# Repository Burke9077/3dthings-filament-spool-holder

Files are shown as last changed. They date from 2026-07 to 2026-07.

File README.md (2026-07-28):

# Parametric filament spool holder

A compact, open-frame filament spool holder designed in OpenSCAD. It takes the
useful layout of common laser-cut desktop holders—a spool axle between two side
frames—and redesigns it as a support-free multipart FDM print.

The model is intentionally unbranded and omits cosmetic panels. Material is
placed only around the load paths, axle cradles, rail sockets, and narrow bottom
ties.

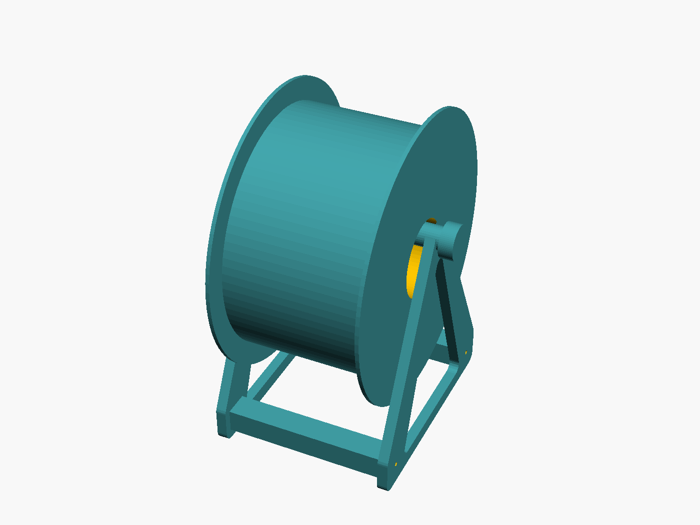
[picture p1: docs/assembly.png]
Rendered assembly


## Browser customizer

Use the hosted customizer at
[burke9077.github.io/3dthings-filament-spool-holder](https://burke9077.github.io/3dthings-filament-spool-holder/).
Set the spool outside diameter, center-hole diameter, and outside width; choose
one to four linked holders; then download the complete print-pack ZIP. The
holder adds side clearance and raises the axle until the complete spool
envelope clears both unchanged crossrails and the table. Advanced controls
expose those clearances, print-bed size, axle diameter, M3 nut dimensions, and
part-fit clearances.

The live 3D assembly rebuilds automatically after settings change. The
part-fit clearance preset changes only mating tolerances—rail sockets, nut
pockets, screw bores, axle caps, and link clips—not print speed, layers,
infill, or strength.

Optional downloads for the nut-fit test, one holder module, link clips, and
individual replacement parts are kept under a secondary menu. Each ZIP carries
the outside diameter, maximum bore, spool width, base depth, crossrail
clearance, and copy counts in its filenames and manifest. The on-page guide
covers print orientation and assembly.

The customizer runs the official OpenSCAD WebAssembly build entirely in the
browser. Dimensions and generated geometry stay on the device; there is no
model-generation server.

## Features

- Parameterized spool outside diameter, center-hole diameter, outside width,
  base depth, rigid-part clearances, frame, axle, fit, and M3 hardware
  dimensions
- Collision-aware axle height derived against the table and complete
  crossrail top plane, with analytic assertions and mesh-level regression
  checks
- Two identical side frames and two identical crossrails
- Shouldered rail tenons that seat in blind inside-face frame sockets
- Drop-in M3 hex-nut traps that become captive inside those sockets
- Removable printed axle with press-fit end caps
- Repeatable side-by-side link clips that preserve independent spool changes
- Flat, support-free print orientations for every part
- Small nut-fit test piece for calibrating a printer before committing to the rails
- Automatically updating browser-side 3D preview
- OpenSCAD Customizer support and command-line STL export

The defaults accept a spool up to 220 mm outside diameter, 60 mm center hole,
and 115 mm outside width. Five millimeters beside each face produces 125 mm
between the frames. The generator guarantees at least 15 mm above the complete
crossrail top plane; that constraint governs the default axle-center height of
172 mm. The worst-case spool bottom is therefore 41 mm above the table and
15 mm above the 26 mm crossrails. The assembly preview shows that maximum
envelope hanging from the axle, just as the physical spool does.

Both diameters matter. The axle supports the upper inside edge of the spool
hole, so the spool center hangs below the axle by half the difference between
the hole and axle diameters. The spool must also clear the crossrails, not
merely the table. The design therefore uses:

```text
spool radius       = outside diameter / 2
rail top           = rail center height + rail height / 2

floor-limited center = spool radius + floor clearance
rail-limited center  = rail top + spool radius + rail clearance

spool center = max(floor-limited center, rail-limited center)
axle height  = spool center
             + (center-hole diameter - axle diameter) / 2
```

The rail rule deliberately treats the entire horizontal plane at the
crossrails' top surface as occupied. This is more conservative than relying on
their lateral position and guarantees that the spool's lowest point clears
both rails even with a non-ideal printed flange. Enter the largest outside
diameter, center hole, and width among the spools you intend to use. Every
spool hole must also be larger than the selected axle diameter.

## Bill of materials

| Item | Quantity | Notes |
| --- | ---: | --- |
| Side frame | 2 | Identical prints |
| Crossrail | 2 | Identical prints; nut openings face upward |
| Axle | 1 | Printed horizontally |
| Axle cap | 2 | Press fit; print closed face on the bed |
| Link clip | 2 per adjacent pair | Optional; one front and one rear |
| M3 hex nut | 4 | Standard 5.5 mm across-flats nut |
| M3 × 10 mm socket-head screw | 4 | M3 × 8 mm also works with most nuts |

## Generate the parts

Open `filament_spool_holder.scad`, choose a value for `part` in the Customizer,
then render and export the STL. Print the quantities listed above.

From a shell with OpenSCAD installed:

```sh
make stls
```

Generated files go into `build/`, which is intentionally not committed. To
regenerate the documentation render:

```sh
make preview
```

## Release preparation

Marketplace publication is held until a complete physical print has been
assembled and approved. The manually triggered **Prepare release** workflow
builds an inspectable release candidate by default; it cannot create a public
GitHub Release without the physical-test confirmation.

See [PUBLISHING.md](PUBLISHING.md) for the release gate, marketplace research,
and first-publication checklist. Build the same candidate locally with:

```sh
make release
```

## Calibrate before printing

Print `build/nut_fit_test.stl` first:

```sh
make build/nut_fit_test.stl
```

A nut should drop into the top opening without rotating in its hex pocket, and
an M3 screw should pass through the horizontal bore. Adjust
`m3_nut_clearance` or `m3_hole_diameter` if needed. The defaults target a
reasonably tuned FDM printer; dimensional behavior varies by material and
machine. In the browser customizer, choose **Extra clearance** when mating
parts bind or **Reduced clearance** when they feel loose.

## Suggested print settings

- 0.20 mm layer height
- 4 top and bottom layers
- 25% gyroid or cubic infill
- PLA, PETG, or ASA
- No supports

Print each side frame flat with its two shallow rail recesses upward. Print each
rail on its broad face with both nut openings upward. The axle has a faceted
flat and is already oriented horizontally; a brim can help with low-adhesion
materials. Print caps with the closed flange against the bed and the socket
upward.

## Assembly

1. Set both crossrails down with their nut openings facing up.
2. Drop an M3 nut into each of the four hex pockets.
3. Seat both shouldered tenons in the shallow recesses on one side frame, then
   add the second frame with its recesses facing inward.
4. Install the four M3 screws through the small holes on the outside faces.
   Square the holder on a flat surface and tighten them evenly.
5. Slide the axle through the spool and lower it into the open cradles. Confirm
   that the axle bears on the upper inside edge of the spool hole while the
   spool clears the floor and both crossrails, then press a cap onto each end.

The blind side-frame sockets cover the nut openings after assembly, so the nuts
cannot escape or turn. The rail shoulders bear against the inside frame faces;
tightening each screw therefore clamps the joint instead of merely retaining
it.

## Link two or more holders

Keep each holder complete, including both side frames and its own axle. Put two
holders side by side, leaving the facing outside frames separated by
`link_gap`, then press one link clip over the two front frame edges and a second
clip over the rear edges. The rounded lower frame corners locate the clips
vertically.

The default 32 mm gap leaves clearance between two facing axle caps. Each
additional holder needs two more clips:

| Holders | Link clips |
| ---: | ---: |
| 1 | 0 |
| 2 | 2 |
| 3 | 4 |
| 4 | 6 |

This deliberately keeps each axle independent. A shared center frame or single
long axle would save one frame, but changing one spool would disturb its
neighbor.

## Important parameters

| Parameter | Default | Purpose |
| --- | ---: | --- |
| `spool_max_diameter` | 220 mm | Largest supported spool outside diameter |
| `spool_max_bore_diameter` | 60 mm | Largest supported spool center hole; contributes to axle height |
| `spool_max_width` | 115 mm | Largest supported width across both outside flanges |
| `spool_side_clearance` | 5 mm/side | Added beside the spool; derives 125 mm clear frame spacing |
| `base_depth` | 175 mm | Front-to-back footprint |
| `spool_floor_clearance` | 15 mm | Minimum vertical gap above the table |
| `spool_rail_clearance` | 15 mm | Minimum vertical gap above the complete crossrail top plane |
| `frame_thickness` | 8 mm | Thickness of each flat side frame |
| `frame_web` | 14 mm | Minimum structural web around the large cutout |
| `axle_diameter` | 18 mm | Printed axle diameter |
| `axle_facets` | 32 | Round axle profile with a narrow printable flat |
| `rail_fit_clearance` | 0.30 mm | Per-side clearance in frame sockets |
| `m3_nut_clearance` | 0.25 mm | Per-side nut-pocket clearance |
| `axle_cap_fit_clearance` | 0.25 mm | Diametral cap socket clearance |
| `link_gap` | 32 mm | Gap between linked modules |
| `link_fit_clearance` | 0.15 mm | Per-side clearance around linked frames |
| `holder_count` | 2 | Complete modules shown in `linked_assembly` |

Changing the outside diameter, center hole, base depth, or either rigid-part
clearance automatically updates the side-frame axle height. Changing spool
width or side clearance updates the rail and axle lengths. OpenSCAD assertions
and generated-mesh collision tests reject combinations that would intersect
the table or crossrails, cut rail sockets through the frame, leave too little
material around the axle, or make the spool hole incompatible with the axle.

## License

The design and customizer are licensed under the [MIT License](LICENSE).

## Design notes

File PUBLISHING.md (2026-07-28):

# Publishing

This project stays unpublished on third-party model sites until a complete
physical print has been assembled and approved.

## Release policy

- Pull requests and merges never publish a marketplace listing.
- GitHub Releases are the canonical, versioned source for generated files.
- The **Prepare release** workflow defaults to a build-only candidate.
- Creating a public GitHub Release requires all of:
  - running the workflow from `main`;
  - a semantic version such as `v0.1.0`;
  - enabling the `publish_release` input; and
  - entering the exact confirmation `PHYSICALLY_TESTED`.
- Publishing or updating Thingiverse and Printables remains a separate,
  deliberate operation.

This keeps a code review or routine Pages deployment from becoming a product
release.

## Build a release candidate

Open **Actions → Prepare release → Run workflow**.

For a build-only rehearsal:

1. Leave `version` as `unreleased`.
2. Leave `publish_release` disabled.
3. Run the workflow.
4. Download and inspect the `spool-holder-release-unreleased` artifact.

The artifact contains the default 220 mm outside-diameter × 60 mm maximum-bore
× 115 mm spool-width STLs (125 mm clear frame spacing), OpenSCAD source,
renders, listing copy, manifest, checksums, and a complete two-holder ZIP.
Geometry-coded filenames include spool width, base depth, and crossrail
clearance so incompatible wall sets remain distinct; each STL filename also
carries its default slicer copy count. It is not a GitHub Release and does not
upload anything to a model marketplace.

The same package can be built locally:

```sh
./scripts/build-release.sh unreleased
```

## First public release

After the physical acceptance print succeeds:

1. Add clear photos of the assembled holder, loaded spool, nut traps, axle, and
   linked modules.
2. Update [`publishing/LISTING.md`](publishing/LISTING.md) with any lessons from
   the print.
3. Run a build-only candidate using the intended version, such as `v0.1.0`.
4. Inspect every STL, image, manifest entry, checksum, and the packaged source.
5. Re-run **Prepare release** from `main` with:
   - `version`: the inspected semantic version;
   - `publish_release`: enabled; and
   - `confirmation`: `PHYSICALLY_TESTED`.
6. Review the resulting GitHub Release before creating marketplace drafts.

## Thingiverse

Thingiverse has an official OAuth2 API that can create and patch Things, upload
files and images, and publish a completed Thing:

- [Thingiverse API getting started](https://www.thingiverse.com/developers/getting-started)
- [Thingiverse upload guide](https://www.thingiverse.com/developers/upload-guide)

There is no mature GitHub Action worth trusting with the account token today.
The closest general-purpose deployer,
[Threedeploy](https://github.com/Chrismettal/Threedeploy), labels itself WIP and
notes that description updates are broken. The newer
[`thingiverse-client`](https://github.com/nomike/thingiverse-client) project is
an alpha SDK and still exposes the multi-step upload flow at a low level.

For the first release, create and review a Thingiverse draft manually using the
GitHub Release assets. Record its Thing ID only after the draft is correct.
That gives a safe target against which a small first-party sync script can be
tested before any automated publish operation is enabled.

## Printables

Printables does not document a supported public write API for creating or
updating model listings. Its official guidance uses the website upload flow.
Community scripts rely on private GraphQL operations or stored browser
sessions, which are fragile and inappropriate for a long-lived repository
secret.

Upload the inspected GitHub Release assets manually. Printables has also
offered a Thingiverse import flow that creates drafts, which can reduce the
initial data entry if it is still available when this project launches. Prusa
has [documented that import
flow](https://blog.prusa3d.com/winter-contest_31019/). Always
review the imported draft and upload the physical photos before publishing.

Until Printables offers a supported write API, manual publication is the
reliable path.

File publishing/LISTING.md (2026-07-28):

# Parametric filament spool holder

> Copy-ready marketplace text. Update it after the physical acceptance print
> and add real photos before publishing.

## Short summary

A compact, support-free filament spool holder with captive M3 nut pockets,
independent axles, and optional clips for linking multiple holders. Customize
the spool outside diameter, center-hole diameter, width, fit, and module count
directly in a browser.

## Description

This open-frame holder is a multipart FDM design built in OpenSCAD. It keeps
material around the load paths while omitting cosmetic panels and branding.

Each holder remains a complete independent module. Two clips connect each
adjacent pair, so one spool can be changed without disturbing its neighbor.
The generator derives frame spacing and axle height from the full spool
envelope. It keeps the spool's lowest point above the complete crossrail top
plane by the configured safety gap rather than relying on rail position or
checking floor clearance alone.

The browser customizer generates the configured STLs locally:

https://burke9077.github.io/3dthings-filament-spool-holder/

The editable OpenSCAD source and release history are available here:

https://github.com/Burke9077/3dthings-filament-spool-holder

## Printed parts

Per holder:

- 2 side frames
- 2 crossrails
- 1 axle
- 2 axle caps

Additional parts:

- 2 link clips per adjacent holder pair
- 1 nut-fit test before printing the structural parts

## Hardware

Per holder:

- 4 M3 hex nuts
- 4 M3 × 10 mm socket screws

## Print notes

- 0.20 mm layer height
- 4 top and bottom layers
- 25% gyroid or cubic infill
- PLA, PETG, or ASA
- No supports

Print the nut-fit test with the intended material and profile first. Side
frames print flat with their shallow rail recesses upward. Crossrails print on
their broad face with the nut openings upward. Print the axle horizontally,
caps flange-down, and clips flat.

## Assembly

1. Place both crossrails with their nut openings upward.
2. Drop one M3 nut into each of the four hex pockets.
3. Seat both rails in one side frame, then add the second frame with its
   shallow recesses facing inward.
4. Install and evenly tighten four M3 screws on a flat surface.
5. Pass the axle through the spool and lower it into the cradles. Confirm the
   axle bears on the upper inside edge of the center hole while the spool
   clears the floor and both crossrails, then add both caps.
6. For multiple holders, connect neighboring frames with one front and one
   rear link clip.

## Suggested tags

`filament`, `spool holder`, `3d printer`, `openscad`, `parametric`, `modular`,
`m3`, `support free`

## License

MIT. See the included `LICENSE` file.

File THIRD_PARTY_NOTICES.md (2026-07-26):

# Third-party notices

The GitHub Pages customizer distributes the official OpenSCAD WebAssembly
runtime so STL generation can happen locally in a browser.

- Component: OpenSCAD WebAssembly runtime
- Version: 2026.07.24 snapshot
- Project: <https://github.com/openscad/openscad>
- Binary source: <https://files.openscad.org/snapshots/OpenSCAD-2026.07.24-WebAssembly-web.zip>
- License: GNU General Public License version 2 or later

The build downloads the official binary and license, verifies the published
SHA-256 checksum, and includes both in the deployed Pages artifact. Exact
provenance is also published at
`public/vendor/openscad/SOURCE.txt`.

The customizer itself and the spool-holder design remain MIT licensed. Runtime
licenses do not change the license of generated holder geometry.

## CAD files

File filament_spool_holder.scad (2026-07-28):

/*
 * Parametric multipart filament spool holder
 *
 * SPDX-License-Identifier: MIT
 *
 * Print quantities:
 *   side_frame  x2
 *   crossbar    x2
 *   axle        x1
 *   axle_cap    x2
 *   link_clip   x2 per adjacent holder pair (optional)
 *
 * Hardware:
 *   M3 x 10 mm socket-head screw x4
 *   Standard M3 hex nut x4
 */

// [Output]

// Object to display or export.
part = "assembly"; // [assembly,linked_assembly,side_frame,crossbar,axle,axle_cap,link_clip,nut_fit_test]

// Include a translucent example spool in the assembly view.
show_preview_spool = true;

// [Spool envelope]

// Maximum supported spool outside diameter.
spool_max_diameter = 220; // [120:1:300]

// Largest center-hole diameter among the spools this frame must support.
spool_max_bore_diameter = 60; // [20:1:120]

// Maximum spool width across both outside flanges.
spool_max_width = 115; // [30:1:240]

// Clearance between each spool face and side frame.
spool_side_clearance = 5; // [1:0.5:20]

// Front-to-back footprint of each side frame.
base_depth = 175; // [100:1:300]

// Minimum vertical gap between the spool's lowest point and the table.
spool_floor_clearance = 15; // [2:1:40]

// Minimum vertical gap above the complete crossrail top plane.
spool_rail_clearance = 15; // [2:1:40]

// [Side frames]

// Thickness of each frame when printed flat.
frame_thickness = 8; // [4:0.5:16]

// Structural material around the large side-frame opening.
frame_web = 14; // [8:1:30]

// Radius applied to the side-frame outside corners.
frame_corner_radius = 7; // [2:1:15]

// Height of the vertical lower shoulders before the frame tapers.
frame_shoulder_height = 34; // [20:1:70]

// Height of the narrow tie below the large material-saving opening.
base_tie_height = 11; // [6:1:25]

// Material surrounding the axle cradle.
axle_slot_wall = 7; // [4:1:15]

// [Crossrails]

// Front-to-back size of each rail.
rail_depth = 20; // [12:1:35]

// Vertical size of each rail.
rail_height = 18; // [12:1:30]

// Distance from each end of the base to the rail center.
rail_inset = 16; // [10:1:40]

// Height of each rail center above the table.
rail_center_height = 17; // [10:1:35]

// Clearance on each side of a rail inside its frame socket.
rail_fit_clearance = 0.30; // [0.1:0.05:0.8]

// Depth of the shouldered tenon entering each blind frame socket.
rail_tenon_depth = 4; // [3:0.5:8]

// Reduction on every tenon edge, leaving a load-bearing rail shoulder.
rail_tenon_shoulder = 2.5; // [1.5:0.5:5]

// [Axle and caps]

// Diameter of the removable printed axle.
axle_diameter = 18; // [10:1:30]

// Facets on the support-free axle. Multiples of four give a useful flat.
axle_facets = 32; // [16:4:64]

// Radial clearance between the axle and each open cradle.
axle_slot_clearance = 0.35; // [0.1:0.05:1]

// Axle extending beyond each outside frame face.
axle_overhang = 11; // [6:1:25]

// Outside diameter of each removable axle cap.
axle_cap_diameter = 27; // [15:1:45]

// Length of axle captured inside a cap.
axle_cap_socket_depth = 8; // [4:1:16]

// Closed thickness at the outside end of a cap.
axle_cap_end_thickness = 3; // [2:0.5:8]

// Diametral clearance between the axle and cap socket.
axle_cap_fit_clearance = 0.25; // [0:0.05:0.8]

// [Modular linking]

// Number of complete modules shown in linked_assembly.
holder_count = 2; // [2:1:4]

// Clear distance between the facing outside frames of linked holders.
link_gap = 32; // [20:1:80]

// Height of each front/rear linking clip.
link_clip_height = 10; // [6:1:18]

// Frame-edge depth captured by a linking clip.
link_grip_depth = 5; // [3:0.5:10]

// Material in front of each pair of frame slots.
link_front_wall = 3; // [2:0.5:6]

// Material outside each captured frame.
link_end_wall = 3; // [2:0.5:6]

// Clearance on each side of a frame inside a linking clip.
link_fit_clearance = 0.15; // [0:0.05:0.8]

// [M3 hardware]

// Through-hole diameter for an M3 screw.
m3_hole_diameter = 3.4; // [3.0:0.05:4.2]

// Standard M3 nut width across opposite flats.
m3_nut_across_flats = 5.5; // [5.0:0.05:7.0]

// Standard M3 nut thickness.
m3_nut_thickness = 2.4; // [1.8:0.05:3.5]

// Clearance on each nut-pocket face.
m3_nut_clearance = 0.25; // [0.05:0.05:0.8]

// [Preview spool]

preview_spool_diameter = spool_max_diameter;
preview_spool_width = spool_max_width;
preview_spool_bore = spool_max_bore_diameter;

/* [Hidden] */

epsilon = 0.02;
clearance_test_epsilon = 0.10;
inside_width =
    spool_max_width + 2 * spool_side_clearance;
spool_radius = spool_max_diameter / 2;
spool_center_drop =
    (spool_max_bore_diameter - axle_diameter) / 2;
preview_spool_center_drop =
    (preview_spool_bore - axle_diameter) / 2;
rail_center_offset = base_depth / 2 - rail_inset;
rail_top =
    rail_center_height + rail_height / 2;
floor_limited_spool_center_height =
    spool_radius + spool_floor_clearance;
rail_limited_spool_center_height =
    rail_top + spool_radius + spool_rail_clearance;
spool_center_height =
    max(
        floor_limited_spool_center_height,
        rail_limited_spool_center_height
    );
clearance_test_spool_center_height = spool_center_height;
axle_height =
    spool_center_height + spool_center_drop;
actual_floor_clearance =
    spool_center_height - spool_radius;
actual_rail_vertical_clearance =
    spool_center_height - spool_radius - rail_top;
axle_slot_radius = axle_diameter / 2 + axle_slot_clearance;
frame_top = axle_height + axle_slot_radius + axle_slot_wall;
frame_outer_width = inside_width + 2 * frame_thickness;
rail_total_length = inside_width + 2 * rail_tenon_depth;
rail_tenon_cross_depth = rail_depth - 2 * rail_tenon_shoulder;
rail_tenon_height = rail_height - 2 * rail_tenon_shoulder;
rail_socket_depth = rail_tenon_depth + rail_fit_clearance;
axle_length = frame_outer_width + 2 * axle_overhang;
minimum_link_gap =
    2 * (axle_overhang + axle_cap_end_thickness) + 4;
link_clip_length =
    link_gap + 2 * frame_thickness + 2 * link_end_wall;
link_clip_depth = link_front_wall + link_grip_depth;
link_slot_center_offset = link_gap / 2 + frame_thickness / 2;
link_mount_height = frame_corner_radius;
axle_print_center_z =
    axle_diameter / 2 * cos(180 / axle_facets);
window_corner_radius = min(6, frame_web / 2);
window_half_width =
    rail_center_offset
        - rail_tenon_cross_depth / 2
        - frame_web * 0.60;
window_top = axle_height - axle_slot_radius - axle_slot_wall - 1;
nut_pocket_length = m3_nut_thickness + 2 * m3_nut_clearance;
nut_pocket_width = m3_nut_across_flats + 2 * m3_nut_clearance;
nut_pocket_corner_diameter =
    nut_pocket_width / cos(30);
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

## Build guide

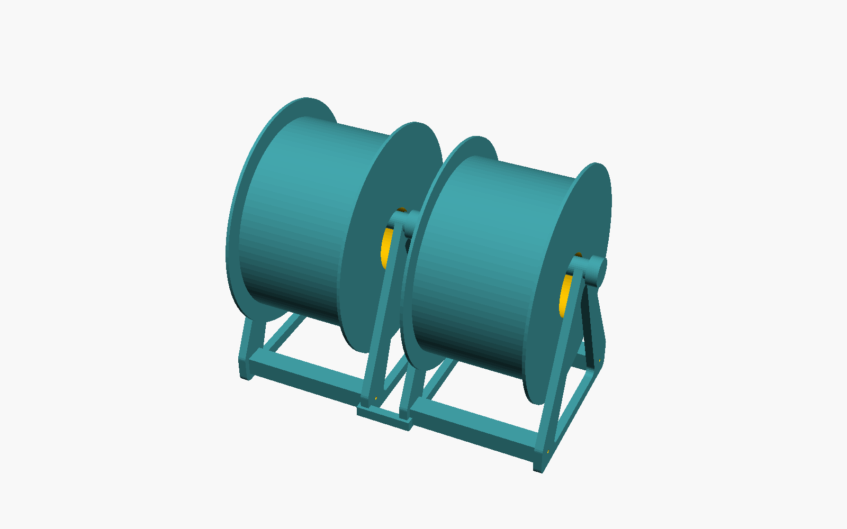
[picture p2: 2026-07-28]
docs/linked-assembly.png

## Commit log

2026-07-26 feat: add parametric modular spool holder
    [filament_spool_holder.scad]
2026-07-26 feat: auto-update preview and clarify fit controls
    [filament_spool_holder.scad]
2026-07-26 fix: clarify complete print downloads
2026-07-27 fix: account for spool bore in axle height
    [filament_spool_holder.scad]
2026-07-27 fix: keep spools above the crossrail top plane
    [filament_spool_holder.scad]
